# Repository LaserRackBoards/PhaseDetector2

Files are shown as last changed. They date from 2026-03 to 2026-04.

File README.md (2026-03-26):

# PhaseDetector2
Phase detector with wide bandwidth, for PDH lock

* SYPD-1, SYPD-2, SYPD-52W phase detector
* [ADC-10-1R](https://www.minicircuits.com/pdfs/ADC-10-1R) directional coupler, 10.5dB coupling, 0.7dB mainline loss
* [BUF602](https://www.ti.com/product/BUF602) buffer amp
* [ADA4898-1](https://www.analog.com/en/products/ada4898-1.html) low noise op-amp
* [LT1568](https://www.analog.com/en/products/lt1568.html) low noise active filter

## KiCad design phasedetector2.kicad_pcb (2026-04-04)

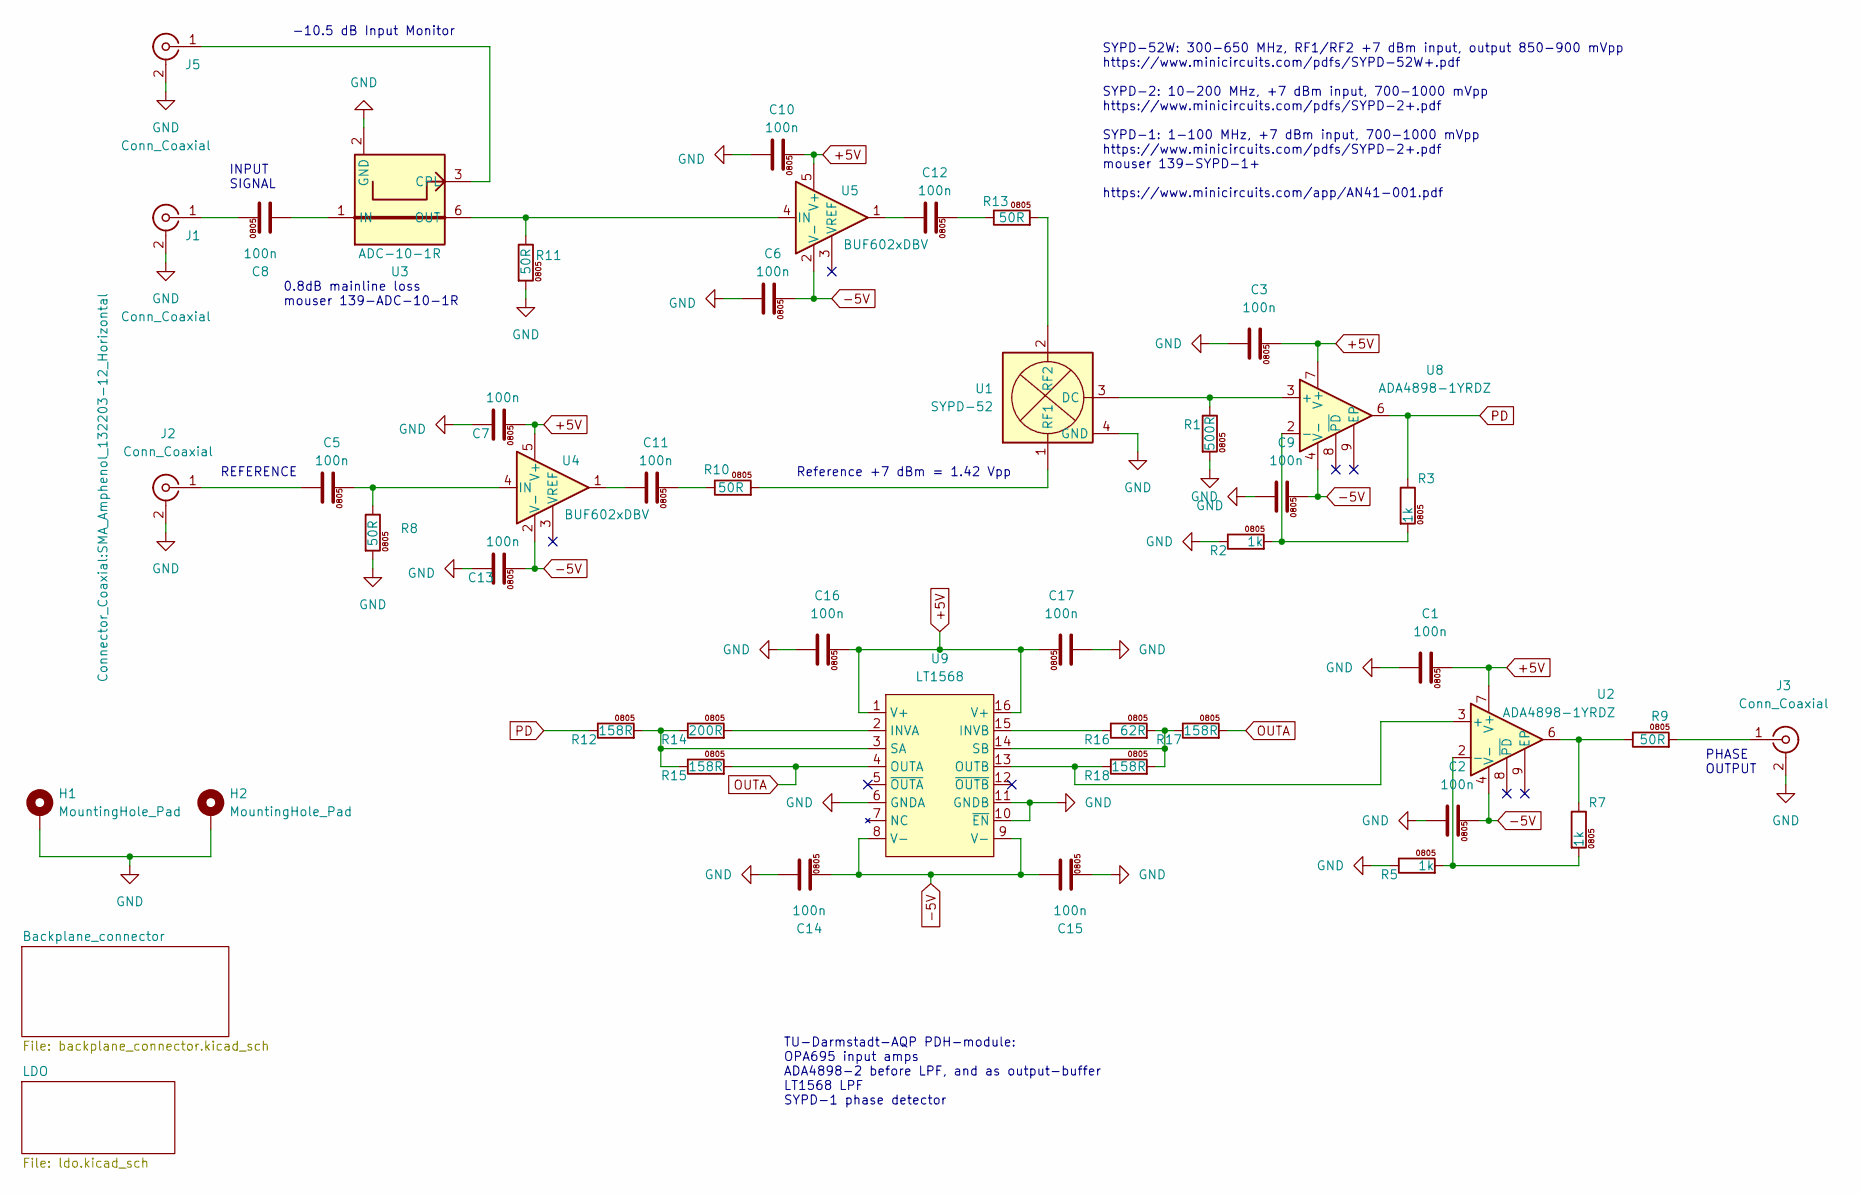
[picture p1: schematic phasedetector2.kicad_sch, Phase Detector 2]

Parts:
C1, C2, C3, C5, C6, C7, C8, C9, C10, C11, C12, C13, C14, C15, C16, C17: 100n; C_0805_2012Metric
H1, H2: MountingHole_Pad; MountingHole_2.7mm_M2.5_DIN965_Pad
J1, J2, J3, J5: Conn_Coaxial; SMA_Amphenol_132203-12_Horizontal
R1: 500R; R_0805_2012Metric
R2, R3, R5, R7: 1k; R_0805_2012Metric
R8, R9, R10, R11, R13: 50R; R_0805_2012Metric
R12, R15, R17, R18: 158R; R_0805_2012Metric
R14: 200R; R_0805_2012Metric
R16: 62R; R_0805_2012Metric
U1: SYPD-52; Mini-Circuits_TTT167_LandPatternPL-079
U2, U8: ADA4898-1YRDZ; SOIC-8-1EP_3.9x4.9mm_P1.27mm_EP2.29x3mm
U3: ADC-10-1R; Mini-Circuits_CD542_LandPatternPL-094
U4, U5: BUF602xDBV; SOT-23-5
U9: LT1568; SSOP-16_3.9x4.9mm_P0.635mm

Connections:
+5V: C1.2, C3.2, C7.2, C10.2, C16.2, C17.2, U2.7 (V+), U4.5 (V+), U5.5 (V+), U8.7 (V+), U9.1 (V+), U9.16 (V+); also elsewhere on the board
-5V: C2.2, C6.2, C9.2, C13.2, C14.2, C15.1, U2.4 (V-), U4.2 (V-), U5.2 (V-), U8.4 (V-), U9.8 (V-), U9.9 (V-); also elsewhere on the board
GND: C1.1, C2.1, C3.1, C6.1, C7.1, C9.1, C10.1, C13.1, C14.1, C15.2, C16.1, C17.1, H1.1, H2.1, J1.2 (Ext), J2.2 (Ext), J3.2 (Ext), J5.2 (Ext), R1.2, R2.1, R5.1, R8.2, R11.2, U1.4 (GND), U1.5 (GND), U1.6 (GND), U3.2 (GND), U3.5 (GND), U9.6 (GNDA), U9.10 (~EN), U9.11 (GNDB); also elsewhere on the board
unnamed: C11.1, U4.1
unnamed: C11.2, R10.1
unnamed: C12.1, U5.1
unnamed: C12.2, R13.1
unnamed: C8.2, J1.1 (In)
unnamed: C5.1, J2.1 (In)
unnamed: J3.1 (In), R9.2
unnamed: J5.1 (In), U3.3 (CPL)
unnamed: R7.1, R9.1, U2.6
unnamed: R1.1, U1.3 (DC), U8.3 (+)
unnamed: R10.2, U1.1 (RF1)
unnamed: R13.2, U1.2 (RF2)
unnamed: R18.1, U2.3 (+), U9.13 (OUTB)
unnamed: R5.2, R7.2, U2.2 (-)
unnamed: C8.1, U3.1 (IN)
unnamed: R11.1, U3.6 (OUT), U5.4 (IN)
unnamed: C5.2, R8.1, U4.4 (IN)
unnamed: R2.2, R3.2, U8.2 (-)
unnamed: R14.2, U9.2 (INVA)
unnamed: R16.1, U9.15 (INVB)
unnamed: R12.2, R14.1, R15.1, U9.3 (SA)
unnamed: R16.2, R17.1, R18.2, U9.14 (SB)
OUTA: R15.2, R17.2, U9.4 (OUTA)
PD: R3.1, R12.1, U8.6

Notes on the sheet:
PHASE OUTPUT
0.8dB mainline loss mouser 139-ADC-10-1R
Reference +7 dBm = 1.42 Vpp
SYPD-52W: 300-650 MHz, RF1/RF2 +7 dBm input, output 850-900 mVpp https://www.minicircuits.com/pdfs/SYPD-52W+.pdf SYPD-2: 10-200 MHz, +7 dBm input, 700-1000 mVpp https://www.minicircuits.com/pdfs/SYPD-2+.pdf SYPD-1: 1-100 MHz, +7 dBm input, 700-1000 mVpp https://www.minicircuits.com/pdfs/SYPD-2+.pdf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
INPUT SIGNAL
REFERENCE
TU-Darmstadt-AQP PDH-module: OPA695 input amps ADA4898-2 before LPF, and as output-buffer LT1568 LPF SYPD-1 phase detector
-10.5 dB Input Monitor

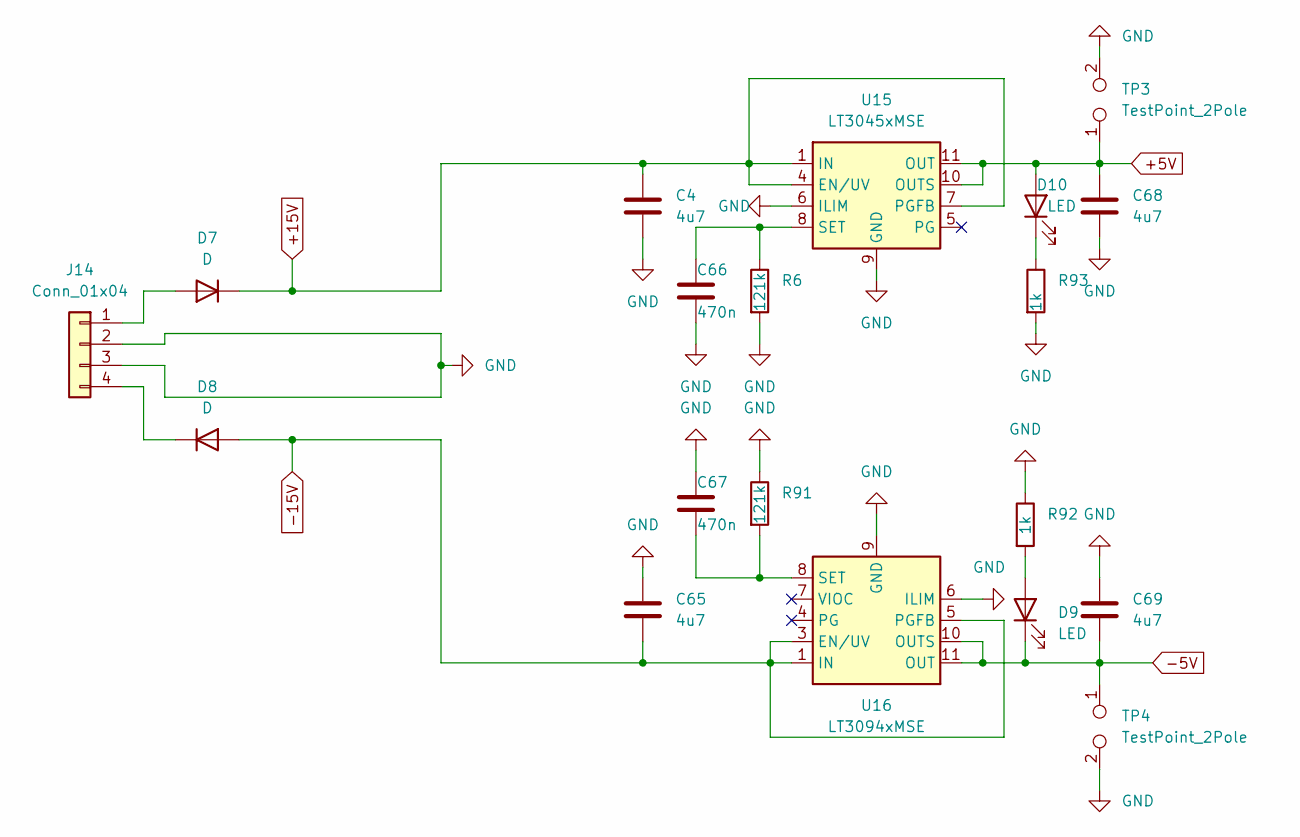
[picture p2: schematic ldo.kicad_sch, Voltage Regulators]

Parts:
C4, C65, C68, C69: 4u7; C_0805_2012Metric
C66, C67: 470n; C_0805_2012Metric
D7, D8: D; D_SMB
D9, D10: LED; LED_0805_2012Metric
J14: Conn_01x04; TerminalBlock_TE_282834-4_1x04_P2.54mm_Horizontal
R6, R91: 121k; R_0805_2012Metric
R92, R93: 1k; R_0805_2012Metric
TP3, TP4: TestPoint_2Pole; TestPoint_2Pads_Pitch2.54mm_Drill0.8mm
U15: LT3045xMSE; MSOP-12-1EP_3x4mm_P0.65mm_EP1.65x2.85mm
U16: LT3094xMSE; MSOP-12-1EP_3x4mm_P0.65mm_EP1.65x2.85mm

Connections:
+5V: C68.1, D10.2 (A), TP3.1, U15.10 (OUTS), U15.11 (OUT), U15.12 (OUT); also elsewhere on the board
+15V: C4.1, D7.1 (K), U15.1 (IN), U15.2 (IN), U15.3 (IN), U15.4 (EN/UV), U15.7 (PGFB); also elsewhere on the board
-5V: C69.2, D9.1 (K), TP4.1, U16.10 (OUTS), U16.11 (OUT), U16.12 (OUT); also elsewhere on the board
-15V: C65.2, D8.2 (A), U16.1 (IN), U16.2 (IN), U16.3 (EN/UV), U16.5 (PGFB), U16.13 (IN); also elsewhere on the board
GND: C4.2, C65.1, C66.2, C67.1, C68.2, C69.1, J14.2, J14.3, R6.2, R91.1, R92.1, R93.2, TP3.2, TP4.2, U15.6 (ILIM), U15.9 (GND), U15.13 (GND), U16.6 (ILIM), U16.9 (GND); also elsewhere on the board
unnamed: D7.2 (A), J14.1
unnamed: D8.1 (K), J14.4
unnamed: D9.2 (A), R92.2
unnamed: D10.1 (K), R93.1
unnamed: C66.1, R6.1, U15.8 (SET)
unnamed: C67.2, R91.2, U16.8 (SET)

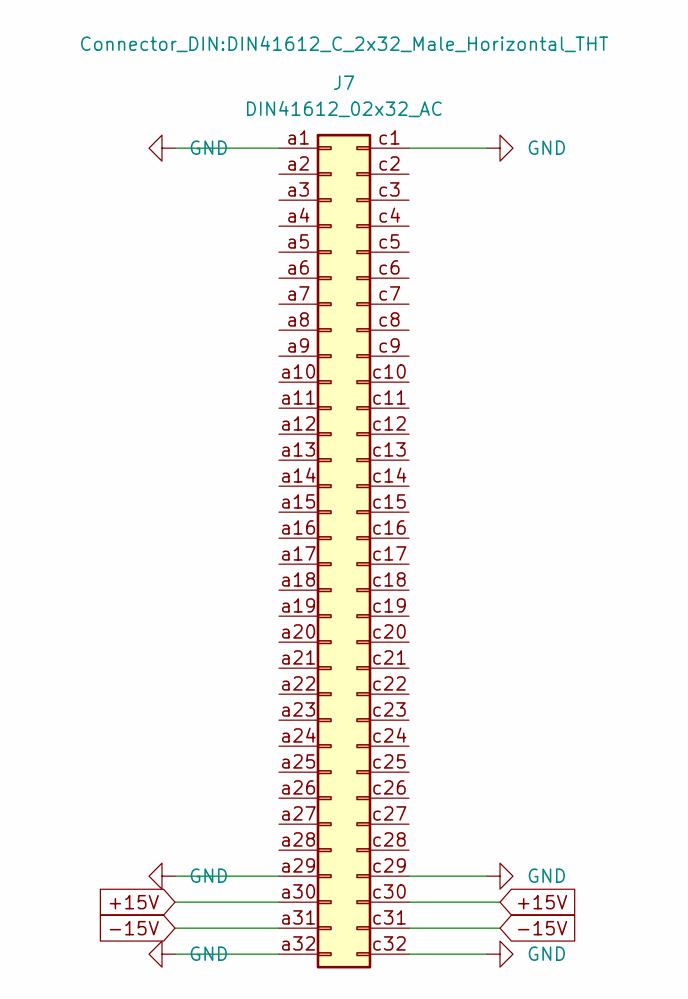
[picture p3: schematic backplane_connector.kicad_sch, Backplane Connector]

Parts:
J7: DIN41612_02x32_AC; DIN41612_C_2x32_Male_Horizontal_THT

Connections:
+15V: J7.a30, J7.c30; also elsewhere on the board
-15V: J7.a31, J7.c31; also elsewhere on the board
GND: J7.a1, J7.a29, J7.a32, J7.c1, J7.c29, J7.c32; also elsewhere on the board

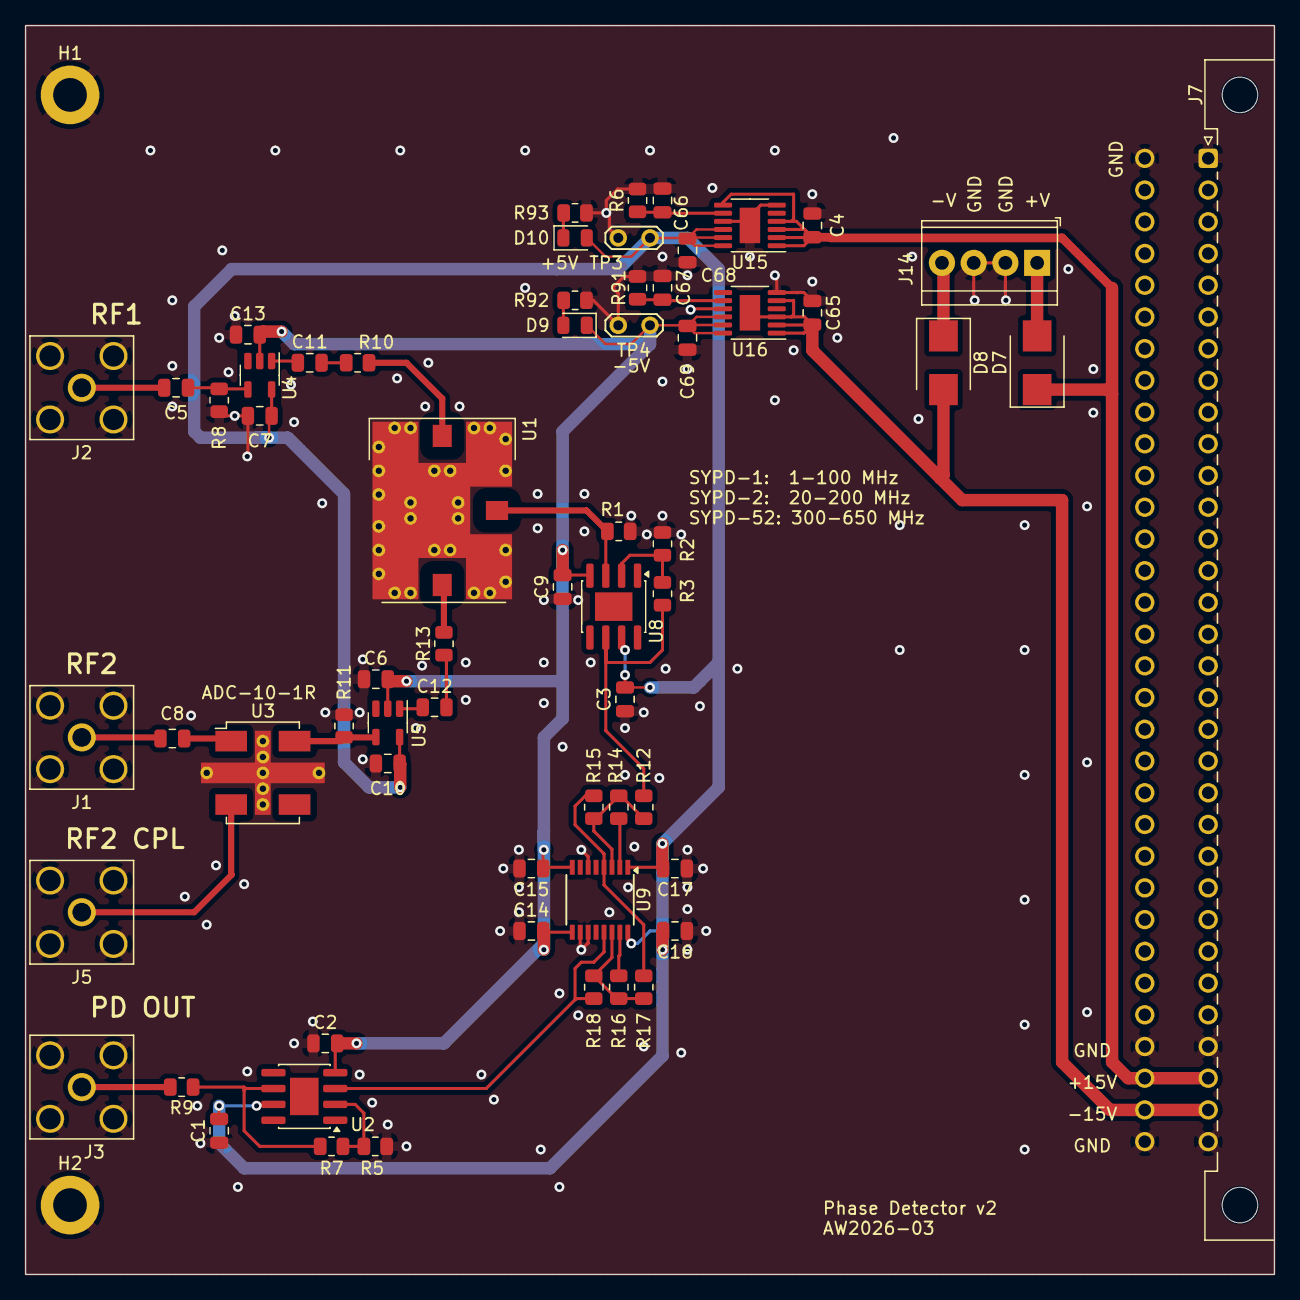
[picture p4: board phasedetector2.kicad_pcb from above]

Board: 2 copper layers, 100.0 x 100.0 mm, 65 parts (0 on the bottom side), 35 nets.
